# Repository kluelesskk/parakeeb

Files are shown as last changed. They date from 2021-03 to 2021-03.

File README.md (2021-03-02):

# Parakeeb Keyboard

A staggered, ortholinear board featuring pretty PCB art and a split 50-key
layout.

The board is designed for ProMicro controllers and requires soldering SMD
diodes. It uses Kailh choc switches and their corresponding "narrow" keycap
footprint (i.e. 17.5 x 16.5 mm - standard Cherry spacing of 18 x 18 mm will
not fit).

The board is reversible and switches can be mounted on either side, and/or
the ProMicro can be soldered upside down. A different firmware has to be
flashed depending on the orientation.

## Credits

- The PCB art was produced using [svg2shenzhen](https://github.com/badgeek/svg2shenzhen).
- The PCB was designed with [Kicad](https://kicad.org).
- The artwork was tweaked with [Inkscape](https://inkscape.org).
- The original artwork was found on [SVG Silh](https://svgsilh.com) and is licensed under
  the Creative Commons CC0 license.
- Some PCB components were adapted from the [Keebio parts library](https://github.com/keebio/Keebio-Parts.pretty)
  and are licensed under the MIT license.
- The logo's font was found on [FontSpace](https://www.fontspace.com/mocking-bird-font-f41547)
  and is subject to a non-commercial license.

## License

This project is released under the MIT license.

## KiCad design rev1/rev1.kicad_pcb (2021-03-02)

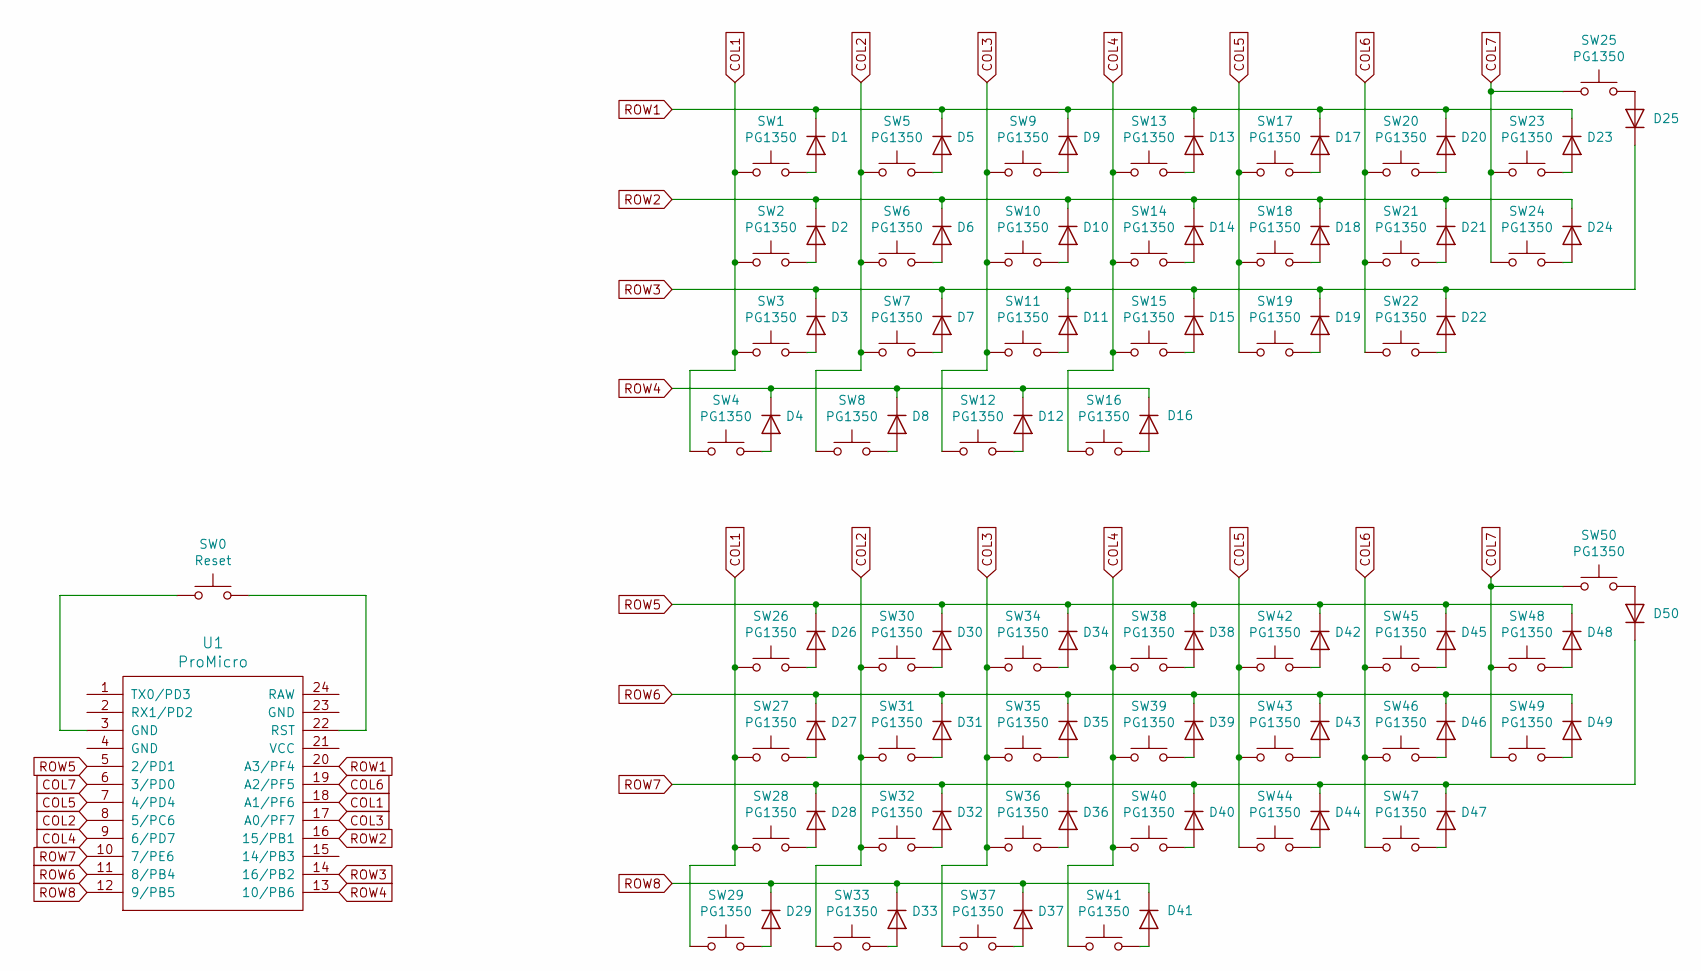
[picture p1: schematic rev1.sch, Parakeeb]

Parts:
D1, D2, D3, D4, D5, D6, D7, D8, D9, D10, D11, D12, D13, D14, D15, D16, D17, D18, D19, D20, D21, D22, D23, D24, D25, D26, D27, D28, D29, D30, D31, D32, D33, D34, D35, D36, D37, D38, D39, D40, D41, D42, D43, D44, D45, D46, D47, D48, D49, D50: D_SMB
SW0: Reset; PushButton
SW1, SW2, SW3, SW4, SW5, SW6, SW7, SW8, SW9, SW10, SW11, SW12, SW13, SW14, SW15, SW16, SW17, SW18, SW19, SW20, SW21, SW22, SW23, SW24, SW25, SW26, SW27, SW28, SW29, SW30, SW31, SW32, SW33, SW34, SW35, SW36, SW37, SW38, SW39, SW40, SW41, SW42, SW43, SW44, SW45, SW46, SW47, SW48, SW49, SW50: PG1350; Kailh-PG1350-1u
U1: ProMicro; ArduinoProMicro

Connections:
COL1: SW1.1, SW2.2, SW3.1, SW4.1, SW26.1, SW27.2, SW28.1, SW29.1, U1.18 (A1/PF6)
COL2: SW5.1, SW6.2, SW7.1, SW8.1, SW30.1, SW31.2, SW32.1, SW33.1, U1.8 (5/PC6)
COL3: SW9.1, SW10.2, SW11.1, SW12.1, SW34.1, SW35.2, SW36.1, SW37.1, U1.17 (A0/PF7)
COL4: SW13.1, SW14.2, SW15.1, SW16.1, SW38.1, SW39.2, SW40.1, SW41.1, U1.9 (6/PD7)
COL5: SW17.1, SW18.1, SW19.1, SW42.1, SW43.1, SW44.1, U1.7 (4/PD4)
COL6: SW20.1, SW21.1, SW22.1, SW45.1, SW46.1, SW47.1, U1.19 (A2/PF5)
COL7: SW23.1, SW24.1, SW25.1, SW48.1, SW49.1, SW50.1, U1.6 (3/PD0)
unnamed: D1.2 (A), SW1.2
unnamed: D2.2 (A), SW2.1
unnamed: D3.2 (A), SW3.2
unnamed: D4.2 (A), SW4.2
unnamed: D5.2 (A), SW5.2
unnamed: D6.2 (A), SW6.1
unnamed: D7.2 (A), SW7.2
unnamed: D8.2 (A), SW8.2
unnamed: D9.2 (A), SW9.2
unnamed: D10.2 (A), SW10.1
unnamed: D11.2 (A), SW11.2
unnamed: D12.2 (A), SW12.2
unnamed: D13.2 (A), SW13.2
unnamed: D14.2 (A), SW14.1
unnamed: D15.2 (A), SW15.2
unnamed: D16.2 (A), SW16.2
unnamed: D17.2 (A), SW17.2
unnamed: D18.2 (A), SW18.2
unnamed: D19.2 (A), SW19.2
unnamed: D20.2 (A), SW20.2
unnamed: D21.2 (A), SW21.2
unnamed: D22.2 (A), SW22.2
unnamed: D23.2 (A), SW23.2
unnamed: D24.2 (A), SW24.2
unnamed: D25.2 (A), SW25.2
unnamed: D26.2 (A), SW26.2
unnamed: D27.2 (A), SW27.1
unnamed: D28.2 (A), SW28.2
unnamed: D29.2 (A), SW29.2
unnamed: D30.2 (A), SW30.2
unnamed: D31.2 (A), SW31.1
unnamed: D32.2 (A), SW32.2
unnamed: D33.2 (A), SW33.2
unnamed: D34.2 (A), SW34.2
unnamed: D35.2 (A), SW35.1
unnamed: D36.2 (A), SW36.2
unnamed: D37.2 (A), SW37.2
unnamed: D38.2 (A), SW38.2
unnamed: D39.2 (A), SW39.1
unnamed: D40.2 (A), SW40.2
unnamed: D41.2 (A), SW41.2
unnamed: D42.2 (A), SW42.2
unnamed: D43.2 (A), SW43.2
unnamed: D44.2 (A), SW44.2
unnamed: D45.2 (A), SW45.2
unnamed: D46.2 (A), SW46.2
unnamed: D47.2 (A), SW47.2
unnamed: D48.2 (A), SW48.2
unnamed: D49.2 (A), SW49.2
unnamed: D50.2 (A), SW50.2
unnamed: SW0.1, U1.3 (GND)
unnamed: SW0.2, U1.22 (RST)
ROW1: D1.1 (K), D5.1 (K), D9.1 (K), D13.1 (K), D17.1 (K), D20.1 (K), D23.1 (K), U1.20 (A3/PF4)
ROW2: D2.1 (K), D6.1 (K), D10.1 (K), D14.1 (K), D18.1 (K), D21.1 (K), D24.1 (K), U1.16 (15/PB1)
ROW3: D3.1 (K), D7.1 (K), D11.1 (K), D15.1 (K), D19.1 (K), D22.1 (K), D25.1 (K), U1.14 (16/PB2)
ROW4: D4.1 (K), D8.1 (K), D12.1 (K), D16.1 (K), U1.13 (10/PB6)
ROW5: D26.1 (K), D30.1 (K), D34.1 (K), D38.1 (K), D42.1 (K), D45.1 (K), D48.1 (K), U1.5 (2/PD1)
ROW6: D27.1 (K), D31.1 (K), D35.1 (K), D39.1 (K), D43.1 (K), D46.1 (K), D49.1 (K), U1.11 (8/PB4)
ROW7: D28.1 (K), D32.1 (K), D36.1 (K), D40.1 (K), D44.1 (K), D47.1 (K), D50.1 (K), U1.10 (7/PE6)
ROW8: D29.1 (K), D33.1 (K), D37.1 (K), D41.1 (K), U1.12 (9/PB5)

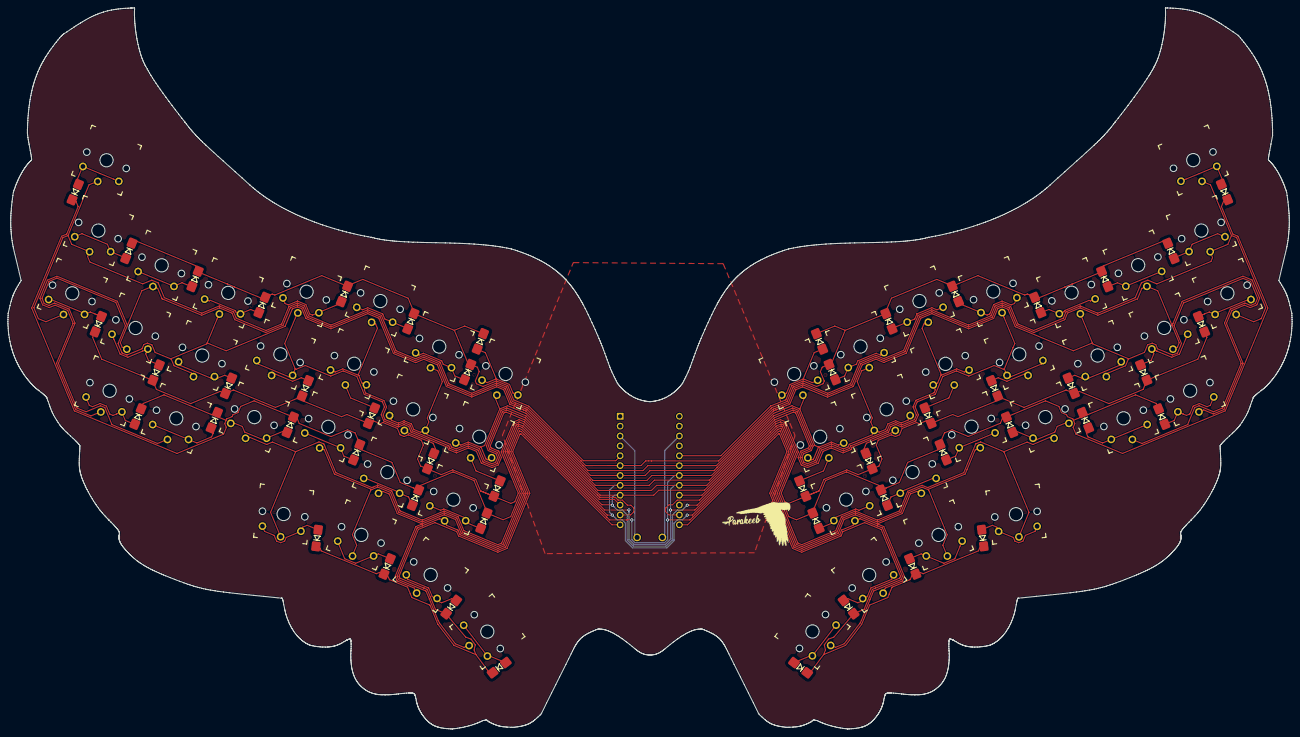
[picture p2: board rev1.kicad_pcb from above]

Board: 2 copper layers, 330.6 x 185.6 mm, 103 parts (0 on the bottom side), 67 nets.

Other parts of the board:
Ref**: Val**; KeyboardDesign
